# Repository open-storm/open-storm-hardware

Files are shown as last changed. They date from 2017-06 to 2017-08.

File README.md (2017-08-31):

# open-storm-hardware
Schematics for open storm hardware.

## perfect cell
**[perfect-cell]** contains Eagle schematics for the _perfect-cell_ board. This board is intended for use with the [perfect-cell](https://github.com/open-storm/perfect-cell) firmware. This board features:

- Cypress CY8C5888LTI-LP097 Programmable System-on-Chip
- Cortex M3 32-bit ARM processor
- 64 KB SRAM
- 256 KB Flash
- Support for Telit cellular modules
- 40 I/O pins for sensors and actuators

Cell Board

## level shifter and relay board
**[level-shifter]** contains Eagle schematics for a level shifter and relay board that can be used to interface the _perfect-cell_ board with higher voltage equipment (such as a valve or autosampler).

Relay board

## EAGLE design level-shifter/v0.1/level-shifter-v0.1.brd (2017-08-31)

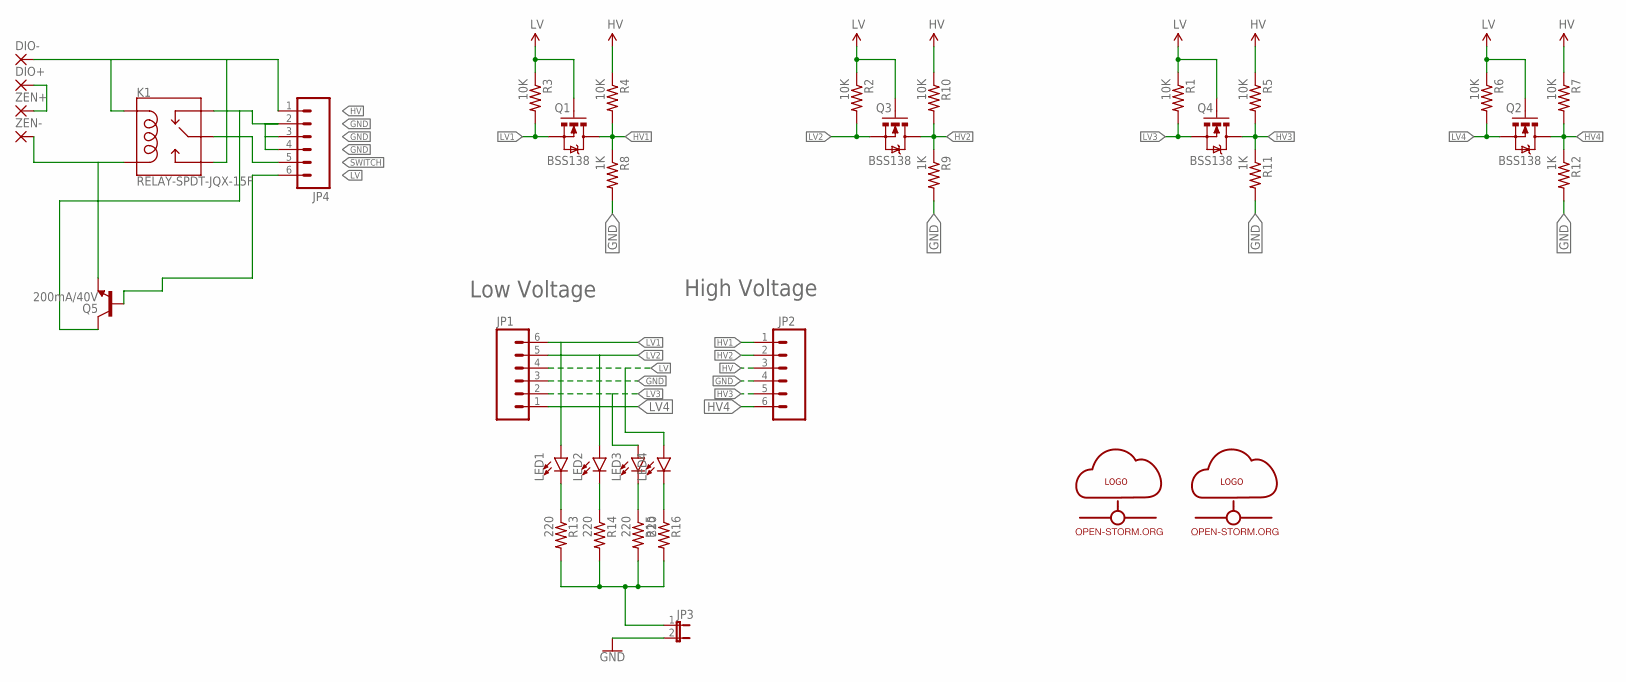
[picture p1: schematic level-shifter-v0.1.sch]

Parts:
DIO+: 2,15/1,0
DIO-: 2,15/1,0
JP1, JP2, JP4: M06SIP; 1X06
JP3: JUMPER-2PTH; 1X02
K1: RELAY-SPDT-JQX-15F; RELAY-T90
LED1, LED2, LED3, LED4: LED5MM; LED_5MM
Q1, Q2, Q3, Q4: BSS138; TO-92
Q5: 200mA/40V; TO-92
R1, R2, R3, R4, R5, R6, R7, R10: 10K; AXIAL-0.4
R8, R9, R11, R12: 1K; AXIAL-0.4
R13, R14, R15, R16: 220; AXIAL-0.4
U$1: OPEN-STORM-LOGO
U$2: OPEN-STORM-LOGO-SMALL
ZEN+: 2,15/1,0
ZEN-: 2,15/1,0

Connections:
GND: JP1.3, JP2.4, JP3.2, JP4.2, JP4.3, JP4.4, K1.NC, Q5.3 (C), R8.P$2 (2), R9.P$2 (2), R11.P$2 (2), R12.P$2 (2)
HV: DIO-.1, JP2.3, JP4.1, K1.COIL1, K1.NO, R4.P$1 (1), R5.P$1 (1), R7.P$1 (1), R10.P$1 (1)
HV1: JP2.1, Q1.1 (D), R4.P$2 (2), R8.P$1 (1)
HV2: JP2.2, Q3.1 (D), R9.P$1 (1), R10.P$2 (2)
HV3: JP2.5, Q4.1 (D), R5.P$2 (2), R11.P$1 (1)
HV4: JP2.6, Q2.1 (D), R7.P$2 (2), R12.P$1 (1)
LV: JP1.4, JP4.6, LED4.A, Q1.3 (G), Q2.3 (G), Q3.3 (G), Q4.3 (G), Q5.2 (B), R1.P$1 (1), R2.P$1 (1), R3.P$1 (1), R6.P$1 (1)
LV1: JP1.6, LED1.A, Q1.2 (S), R3.P$2 (2)
LV2: JP1.5, LED2.A, Q3.2 (S), R2.P$2 (2)
LV3: JP1.2, LED3.A, Q4.2 (S), R1.P$2 (2)
LV4: JP1.1, Q2.2 (S), R6.P$2 (2)
unnamed: DIO+.1, ZEN+.1
unnamed: LED4.K (C), R16.P$1 (1)
unnamed: LED2.K (C), R14.P$1 (1)
unnamed: K1.COIL2, Q5.1 (E), ZEN-.1
unnamed: LED1.K (C), R13.P$1 (1)
unnamed: LED3.K (C), R15.P$1 (1)
unnamed: JP3.1, R13.P$2 (2), R14.P$2 (2), R15.P$2 (2), R16.P$2 (2)
SWITCH: JP4.5, K1.MAIN

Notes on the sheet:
High Voltage
Low Voltage

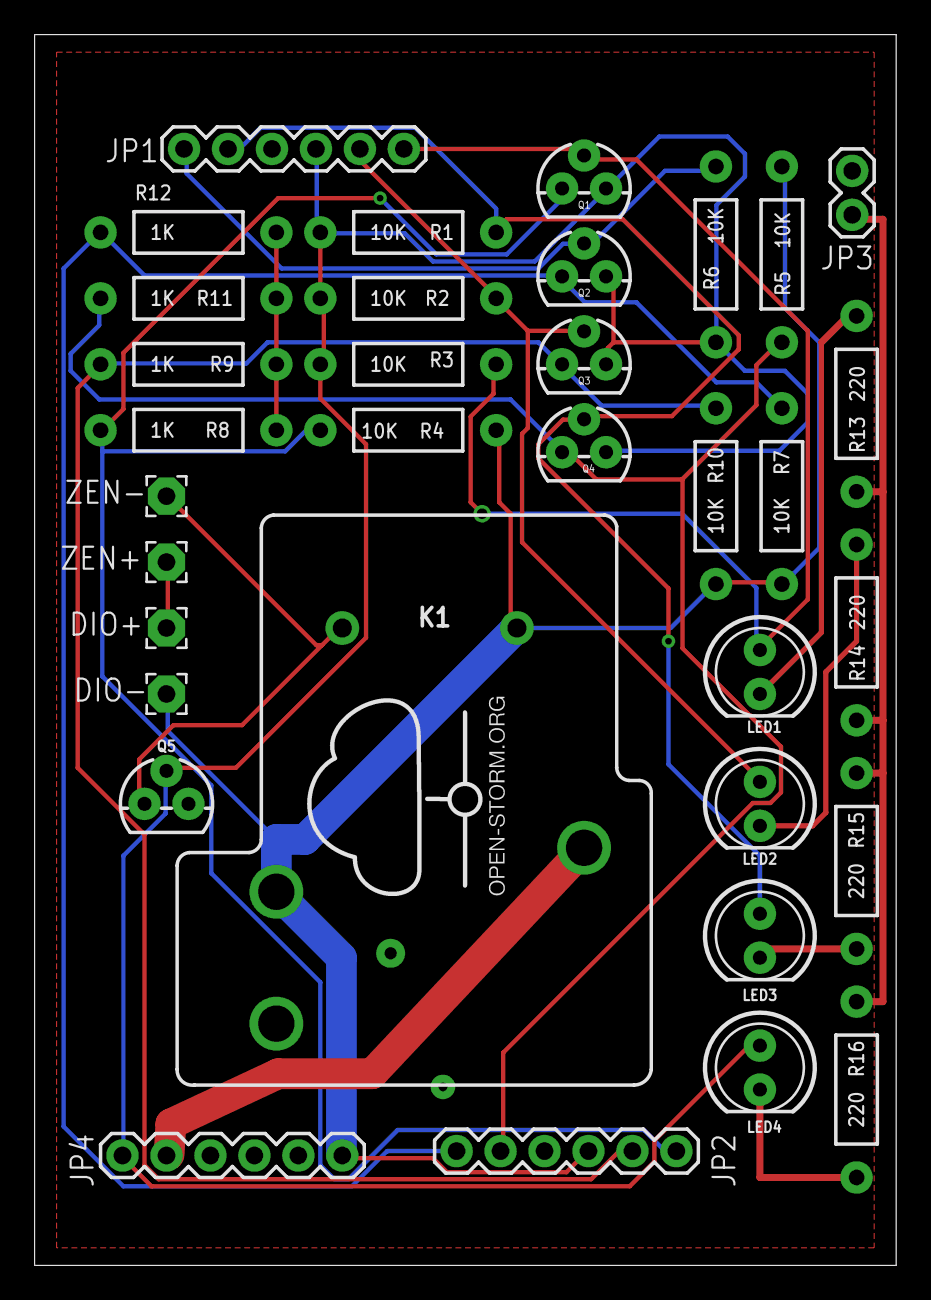
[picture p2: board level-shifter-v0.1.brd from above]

Board: 2 copper layers, 49.8 x 71.1 mm, 36 parts (1 on the bottom side), 19 nets.

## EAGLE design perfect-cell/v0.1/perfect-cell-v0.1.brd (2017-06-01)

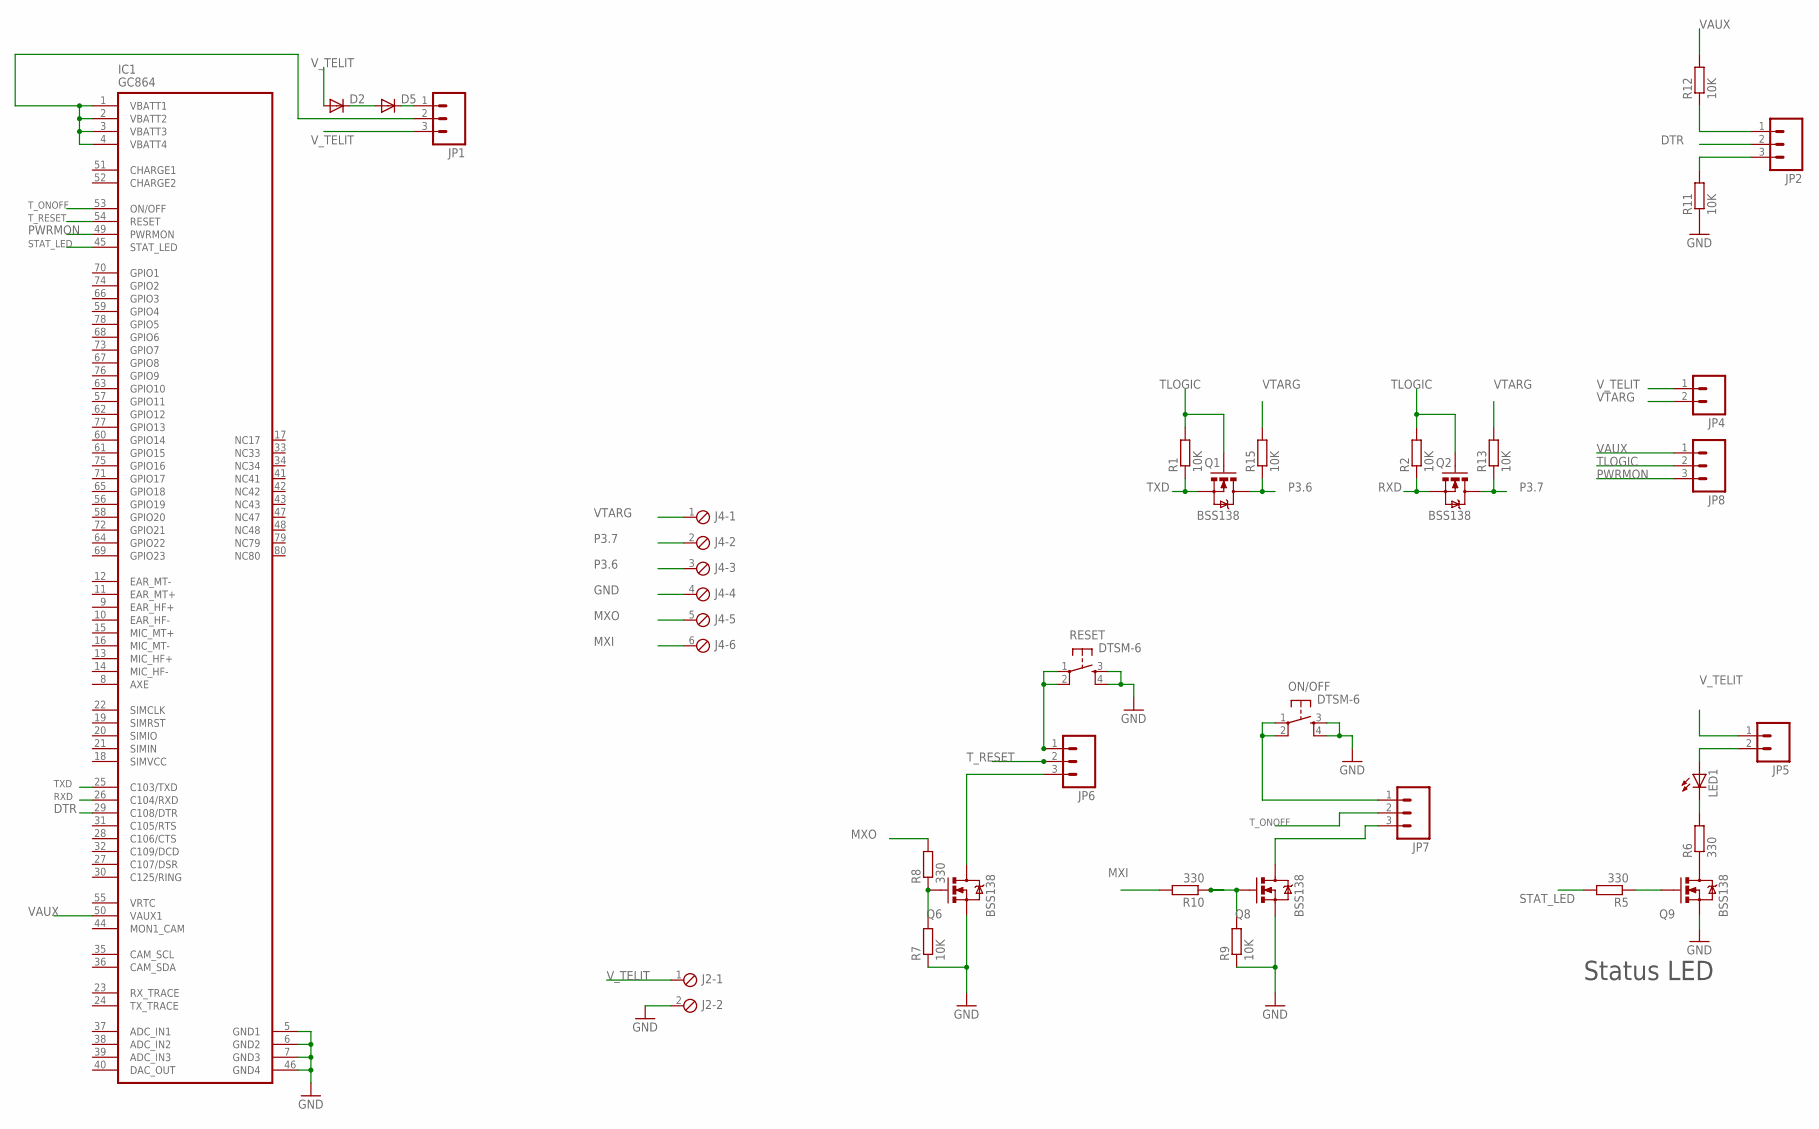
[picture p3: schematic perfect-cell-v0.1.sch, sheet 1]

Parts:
D2, D5: DIODESMA; SMA-DIODE
IC1: GC864
J2: MPT2; 2POL254
J4: MPT6; 6POL254
JP1, JP2, JP6, JP7, JP8: M03LOCK; 1X03_LOCK
JP4, JP5: M02LOCK; 1X02_LOCK
LED1: LEDSML0805; SML0805
ON/OFF: DTSM-6
Q1, Q2, Q6, Q8, Q9: BSS138; SOT23-3
R1, R2, R7, R9, R11, R12, R13, R15: 10K; R0805
R5, R6, R8, R10: 330; R0805
RESET: DTSM-6

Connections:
CHARGE1: IC1.51 (CHARGE1)
CHARGE2: IC1.52 (CHARGE2)
DTR: IC1.29 (C108/DTR), JP2.2
GND: IC1.5 (GND1), IC1.6 (GND2), IC1.7 (GND3), IC1.46 (GND4), J2.2, J4.4, ON/OFF.3, ON/OFF.4, Q6.2 (S), Q8.2 (S), Q9.2 (S), R7.1, R9.1, R11.1, RESET.3, RESET.4; also elsewhere on the board
MXI: J4.6, R10.2; also elsewhere on the board
MXO: J4.5, R8.2; also elsewhere on the board
unnamed: Q6.1 (G), R7.2, R8.1
unnamed: IC1.1 (VBATT1), IC1.2 (VBATT2), IC1.3 (VBATT3), IC1.4 (VBATT4), JP1.2
unnamed: D2.C, D5.A
unnamed: Q9.3 (D), R6.1
unnamed: JP5.2, LED1.A
unnamed: LED1.C, R6.2
unnamed: Q8.1 (G), R9.2, R10.1
unnamed: Q9.1 (G), R5.1
unnamed: JP2.1, R12.1
unnamed: JP2.3, R11.2
unnamed: D5.C, JP1.1
unnamed: JP7.3, Q8.3 (D)
unnamed: JP6.3, Q6.3 (D)
unnamed: JP7.1, ON/OFF.1, ON/OFF.2
unnamed: JP6.1, RESET.1, RESET.2
P3.6: J4.3, Q1.3 (D), R15.1; also elsewhere on the board
P3.7: J4.2, Q2.3 (D), R13.1; also elsewhere on the board
PWRMON: IC1.49 (PWRMON), JP8.3
RXD: IC1.26 (C104/RXD), Q2.2 (S), R2.1
STAT_LED: IC1.45 (STAT_LED), R5.2
TLOGIC: JP8.2, Q1.1 (G), Q2.1 (G), R1.2, R2.2
TXD: IC1.25 (C103/TXD), Q1.2 (S), R1.1
T_ONOFF: IC1.53 (ON/OFF), JP7.2
T_RESET: IC1.54 (RESET), JP6.2
VAUX: IC1.50 (VAUX1), JP8.1, R12.2
VTARG: J4.1, JP4.2, R13.2, R15.2
V_TELIT: D2.A, J2.1, JP1.3, JP4.1, JP5.1; also elsewhere on the board

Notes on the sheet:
Status LED

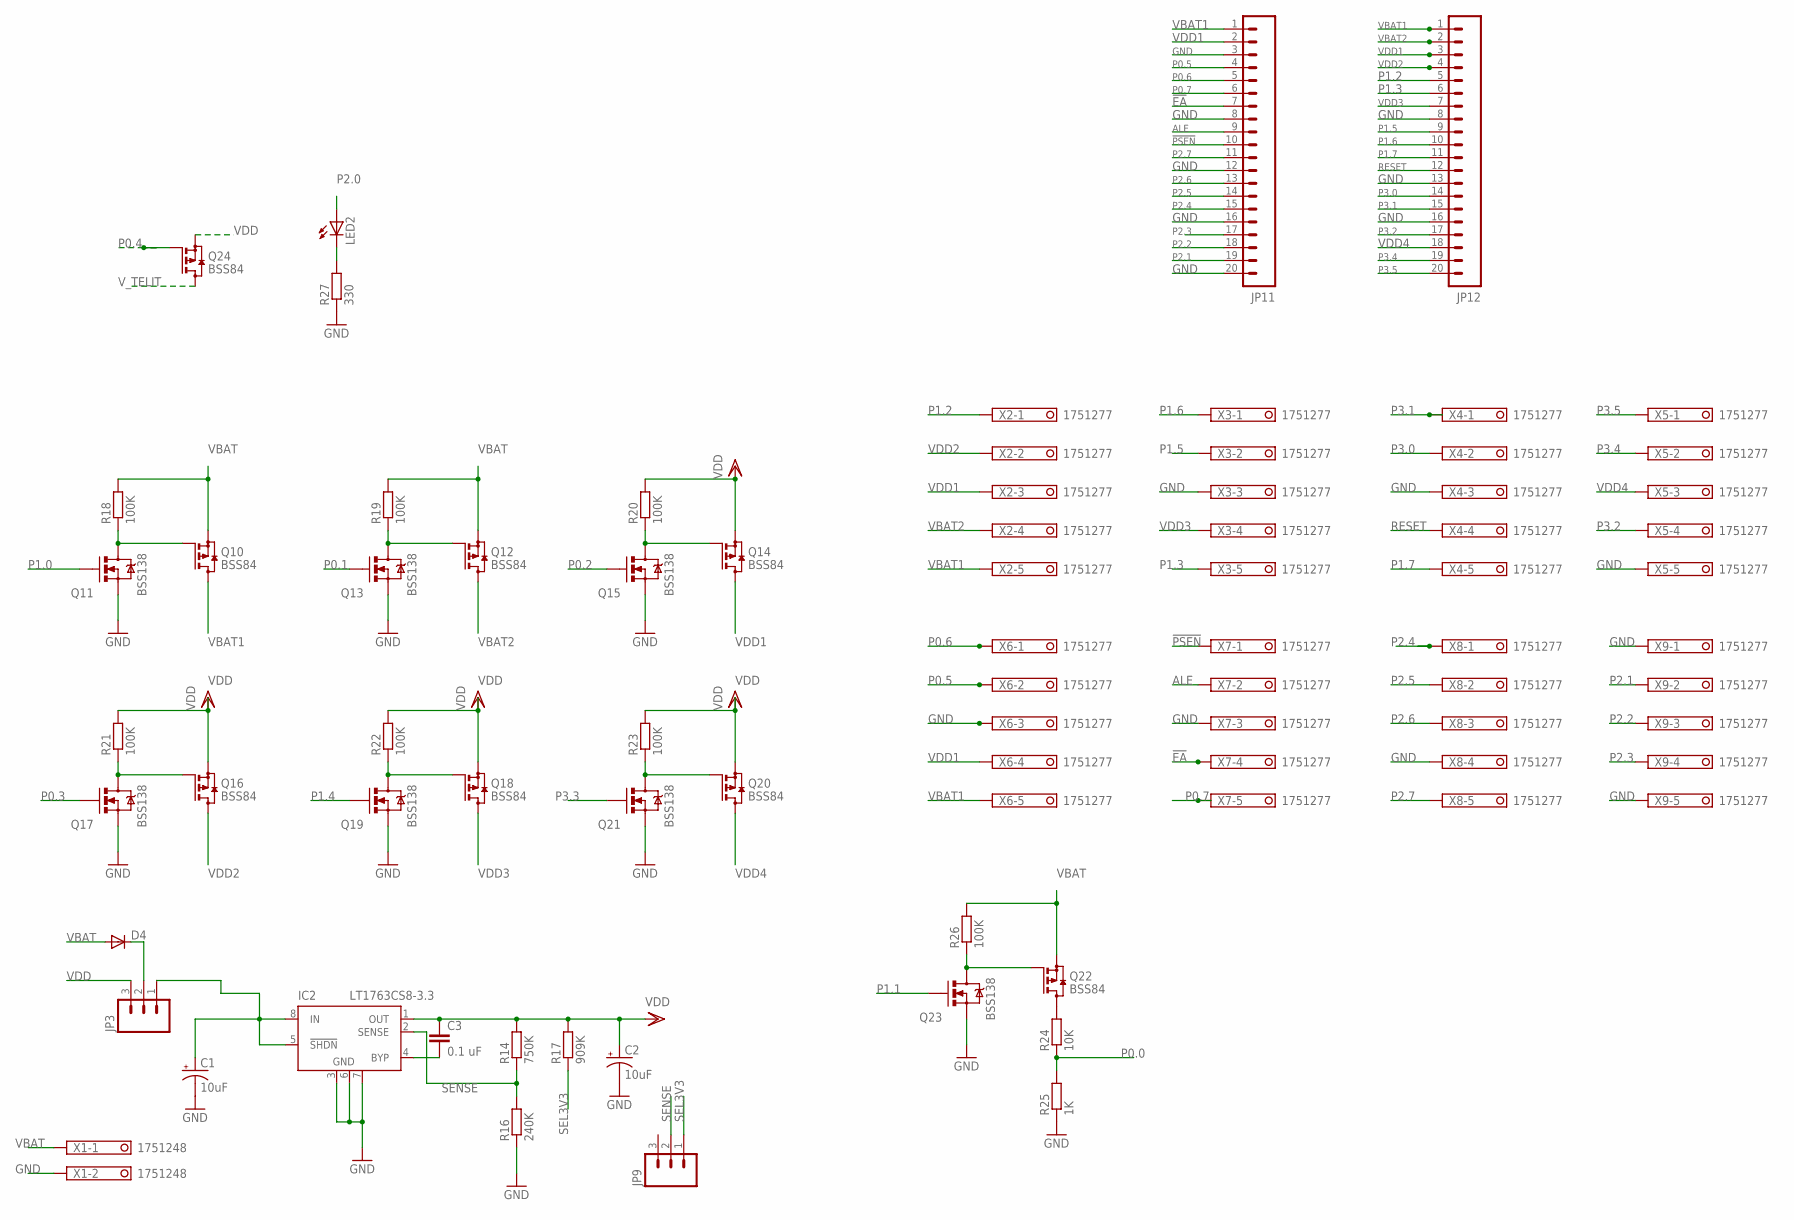
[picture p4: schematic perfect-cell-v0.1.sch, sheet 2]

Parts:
C1, C2: 10uF; EIA3216
C3: 0.1 uF; 0402-CAP
D4: DIODESMA; SMA-DIODE
IC2: LT1763CS8-3.3; SOIC8
JP3, JP9: M03LOCK; 1X03_LOCK
JP11, JP12: M20; 1X20
LED2: LEDSML0805; SML0805
Q10, Q12, Q14, Q16, Q18, Q20, Q22, Q24: BSS84; SOT23
Q11, Q13, Q15, Q17, Q19, Q21, Q23: BSS138; SOT23-3
R14: 750K; R0805
R16: 240K; R0805
R17: 909K; R0805
R18, R19, R20, R21, R22, R23, R26: 100K; R0805
R24: 10K; R0805
R25: 1K; R0805
R27: 330; R0805
X1: 1751248
X2, X3, X4, X5, X6, X7, X8, X9: 1751277

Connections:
!EA: JP11.7, X7.4; also elsewhere on the board
!PSEN: JP11.10, X7.1; also elsewhere on the board
ALE: JP11.9, X7.2; also elsewhere on the board
GND: C1.C (-), C2.C (-), IC2.3 (GND), IC2.6 (GND), IC2.7 (GND), JP11.3, JP11.8, JP11.12, JP11.16, JP11.20, JP12.8, JP12.13, JP12.16, Q11.2 (S), Q13.2 (S), Q15.2 (S), Q17.2 (S), Q19.2 (S), Q21.2 (S), Q23.2 (S), R16.1, R25.1, R27.1, X1.2, X3.3, X4.3, X5.5, X6.3, X7.3, X8.4, X9.1, X9.5; also elsewhere on the board
unnamed: D4.C, JP3.2
unnamed: Q10.1 (G), Q11.3 (D), R18.1
unnamed: C1.A (+), IC2.5 (!SHDN), IC2.8 (IN), JP3.1
unnamed: Q12.1 (G), Q13.3 (D), R19.1
unnamed: C3.2, IC2.4 (BYP)
unnamed: Q14.1 (G), Q15.3 (D), R20.1
unnamed: Q16.1 (G), Q17.3 (D), R21.1
unnamed: Q18.1 (G), Q19.3 (D), R22.1
unnamed: Q20.1 (G), Q21.3 (D), R23.1
unnamed: Q22.1 (G), Q23.3 (D), R26.1
unnamed: Q22.3 (D), R24.2
unnamed: LED2.C, R27.2
P0.0: R24.1, R25.2; also elsewhere on the board
P0.1: Q13.1 (G); also elsewhere on the board
P0.2: Q15.1 (G); also elsewhere on the board
P0.3: Q17.1 (G); also elsewhere on the board
P0.4: Q24.1 (G); also elsewhere on the board
P0.5: JP11.4, X6.2; also elsewhere on the board
P0.6: JP11.5, X6.1; also elsewhere on the board
P0.7: JP11.6, X7.5; also elsewhere on the board
P1.0: Q11.1 (G); also elsewhere on the board
P1.1: Q23.1 (G); also elsewhere on the board
P1.2: JP12.5, X2.1; also elsewhere on the board
P1.3: JP12.6, X3.5; also elsewhere on the board
P1.4: Q19.1 (G); also elsewhere on the board
P1.5: JP12.9, X3.2; also elsewhere on the board
P1.6: JP12.10, X3.1; also elsewhere on the board
P1.7: JP12.11, X4.5; also elsewhere on the board
P2.0: LED2.A; also elsewhere on the board
P2.1: JP11.19, X9.2; also elsewhere on the board
P2.2: JP11.18, X9.3; also elsewhere on the board
P2.3: JP11.17, X9.4; also elsewhere on the board
P2.4: JP11.15, X8.1; also elsewhere on the board
P2.5: JP11.14, X8.2; also elsewhere on the board
P2.6: JP11.13, X8.3; also elsewhere on the board
P2.7: JP11.11, X8.5; also elsewhere on the board
P3.0: JP12.14, X4.2; also elsewhere on the board
P3.1: JP12.15, X4.1; also elsewhere on the board
P3.2: JP12.17, X5.4; also elsewhere on the board
P3.3: Q21.1 (G); also elsewhere on the board
P3.4: JP12.19, X5.2; also elsewhere on the board
P3.5: JP12.20, X5.1; also elsewhere on the board
RESET: JP12.12, X4.4; also elsewhere on the board
SEL3V3: JP9.1, R17.1
SENSE: IC2.2 (SENSE), JP9.2, R14.1, R16.2
VBAT: D4.A, Q10.2 (S), Q12.2 (S), Q22.2 (S), R18.2, R19.2, R26.2, X1.1
VBAT1: JP11.1, JP12.1, Q10.3 (D), X2.5, X6.5
VBAT2: JP12.2, Q12.3 (D), X2.4
VDD: C2.A (+), C3.1, IC2.1 (OUT), JP3.3, Q14.2 (S), Q16.2 (S), Q18.2 (S), Q20.2 (S), Q24.2 (S), R14.2, R17.2, R20.2, R21.2, R22.2, R23.2; also elsewhere on the board
VDD1: JP11.2, JP12.3, Q14.3 (D), X2.3, X6.4
VDD2: JP12.4, Q16.3 (D), X2.2
VDD3: JP12.7, Q18.3 (D), X3.4
VDD4: JP12.18, Q20.3 (D), X5.3
V_TELIT: Q24.3 (D); also elsewhere on the board

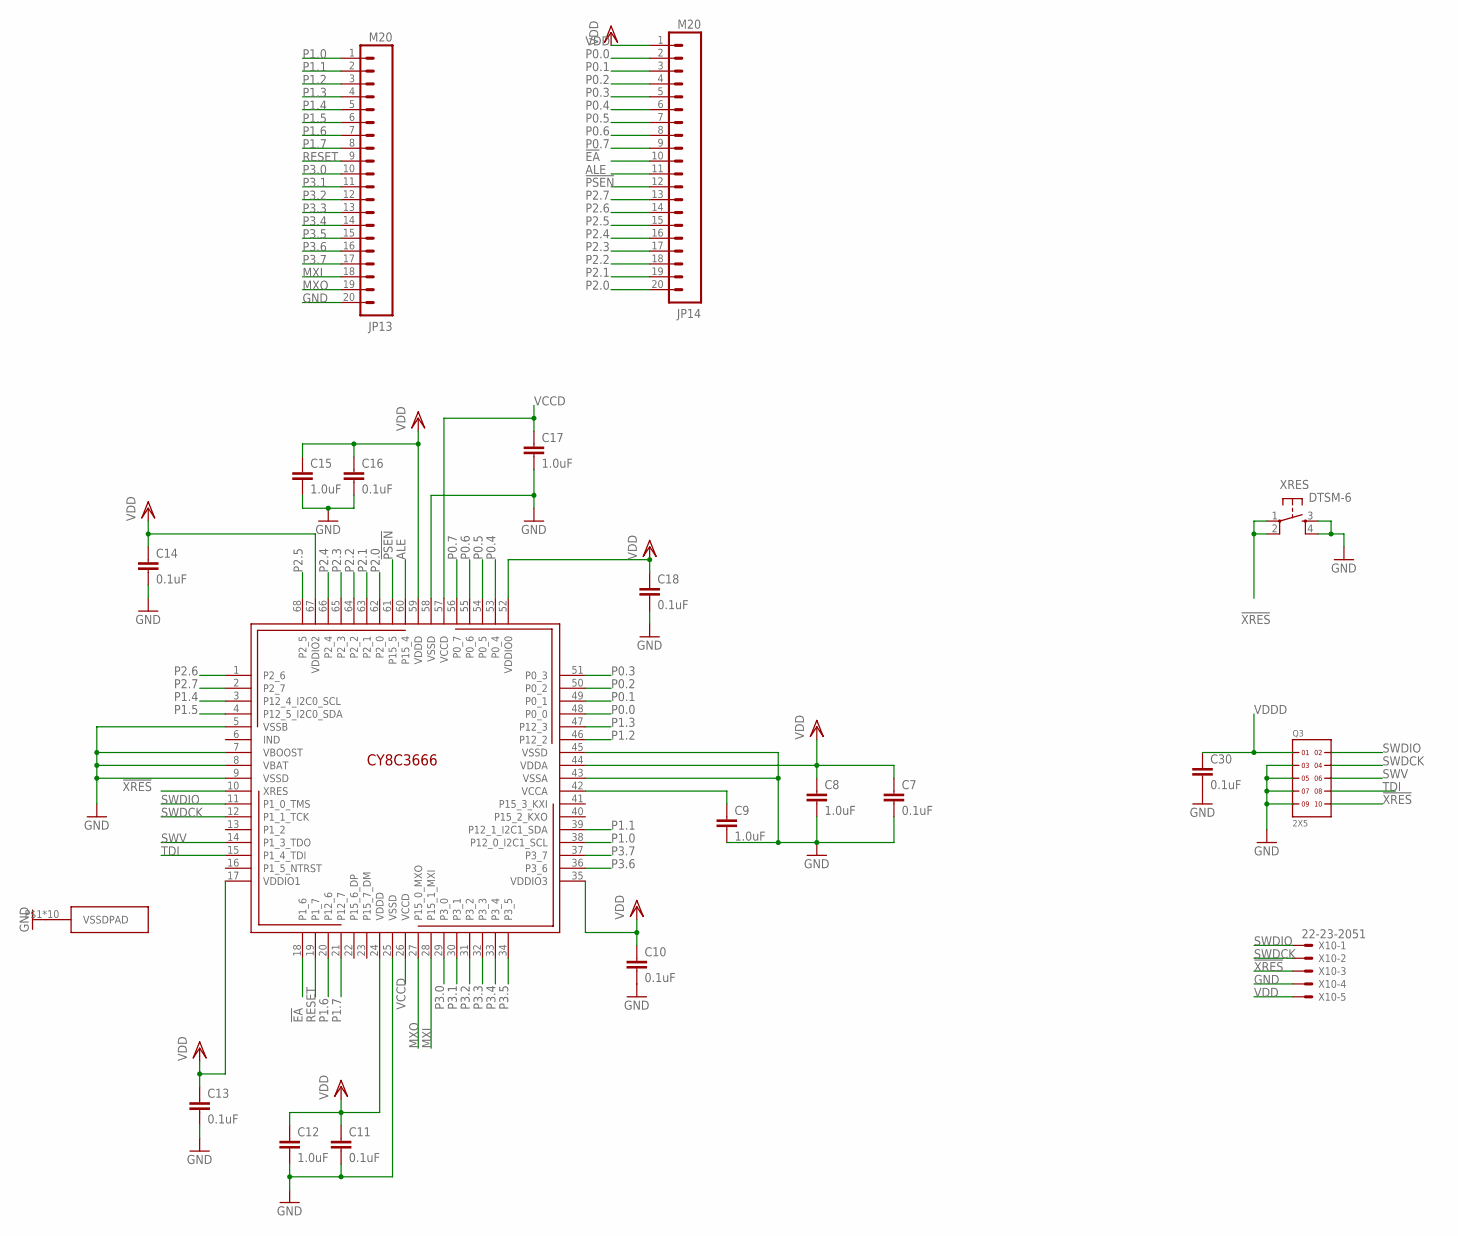
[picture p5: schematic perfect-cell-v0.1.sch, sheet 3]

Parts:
C7, C10, C11, C13, C14, C16, C18, C30: 0.1uF; 0402-CAP
C8, C9, C12, C15, C17: 1.0uF; 0402-CAP
JP13, JP14: M20; 1X20
Q3: 2X5; FTSH-105-01-XXX-DV-K
U$1: CY8C3X66LTI; QFN-68
X10: 22-23-2051
XRES: DTSM-6

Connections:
!EA: JP14.10, U$1.18 (P1_6); also elsewhere on the board
!PSEN: JP14.12, U$1.61 (P15_5); also elsewhere on the board
!XRES: Q3.10, U$1.10 (XRES), X10.3, XRES.1, XRES.2
ALE: JP14.11, U$1.60 (P15_4); also elsewhere on the board
GND: C7.2, C8.2, C9.2, C10.2, C11.2, C12.2, C13.2, C14.2, C15.2, C16.2, C17.2, C18.2, C30.2, JP13.20, Q3.3, Q3.5, Q3.7, Q3.9, U$1.5 (VSSB), U$1.7 (VBOOST), U$1.8 (VBAT), U$1.9 (VSSD), U$1.25 (VSSD), U$1.43 (VSSA), U$1.45 (VSSD), U$1.58 (VSSD), U$1.P$1 (VSSDPAD), U$1.P$2 (VSSDPAD), U$1.P$3 (VSSDPAD), U$1.P$4 (VSSDPAD), U$1.P$5 (VSSDPAD), U$1.P$6 (VSSDPAD), U$1.P$7 (VSSDPAD), U$1.P$8 (VSSDPAD), U$1.P$9 (VSSDPAD), U$1.PAD (VSSDPAD), X10.4, XRES.3, XRES.4; also elsewhere on the board
MXI: JP13.18, U$1.28 (P15_1_MXI); also elsewhere on the board
MXO: JP13.19, U$1.27 (P15_0_MXO); also elsewhere on the board
unnamed: C9.1, U$1.42 (VCCA)
P0.0: JP14.2, U$1.48 (P0_0); also elsewhere on the board
P0.1: JP14.3, U$1.49 (P0_1); also elsewhere on the board
P0.2: JP14.4, U$1.50 (P0_2); also elsewhere on the board
P0.3: JP14.5, U$1.51 (P0_3); also elsewhere on the board
P0.4: JP14.6, U$1.53 (P0_4); also elsewhere on the board
P0.5: JP14.7, U$1.54 (P0_5); also elsewhere on the board
P0.6: JP14.8, U$1.55 (P0_6); also elsewhere on the board
P0.7: JP14.9, U$1.56 (P0_7); also elsewhere on the board
P1.0: JP13.1, U$1.38 (P12_0_I2C1_SCL); also elsewhere on the board
P1.1: JP13.2, U$1.39 (P12_1_I2C1_SDA); also elsewhere on the board
P1.2: JP13.3, U$1.46 (P12_2); also elsewhere on the board
P1.3: JP13.4, U$1.47 (P12_3); also elsewhere on the board
P1.4: JP13.5, U$1.3 (P12_4_I2C0_SCL); also elsewhere on the board
P1.5: JP13.6, U$1.4 (P12_5_I2C0_SDA); also elsewhere on the board
P1.6: JP13.7, U$1.20 (P12_6); also elsewhere on the board
P1.7: JP13.8, U$1.21 (P12_7); also elsewhere on the board
P2.0: JP14.20, U$1.62 (P2_0); also elsewhere on the board
P2.1: JP14.19, U$1.63 (P2_1); also elsewhere on the board
P2.2: JP14.18, U$1.64 (P2_2); also elsewhere on the board
P2.3: JP14.17, U$1.65 (P2_3); also elsewhere on the board
P2.4: JP14.16, U$1.66 (P2_4); also elsewhere on the board
P2.5: JP14.15, U$1.68 (P2_5); also elsewhere on the board
P2.6: JP14.14, U$1.1 (P2_6); also elsewhere on the board
P2.7: JP14.13, U$1.2 (P2_7); also elsewhere on the board
P3.0: JP13.10, U$1.29 (P3_0); also elsewhere on the board
P3.1: JP13.11, U$1.30 (P3_1); also elsewhere on the board
P3.2: JP13.12, U$1.31 (P3_2); also elsewhere on the board
P3.3: JP13.13, U$1.32 (P3_3); also elsewhere on the board
P3.4: JP13.14, U$1.33 (P3_4); also elsewhere on the board
P3.5: JP13.15, U$1.34 (P3_5); also elsewhere on the board
P3.6: JP13.16, U$1.36 (P3_6); also elsewhere on the board
P3.7: JP13.17, U$1.37 (P3_7); also elsewhere on the board
RESET: JP13.9, U$1.19 (P1_7); also elsewhere on the board
SWDCK: Q3.4, U$1.12 (P1_1_TCK), X10.2
SWDIO: Q3.2, U$1.11 (P1_0_TMS), X10.1
SWV: Q3.6, U$1.14 (P1_3_TDO)
TDI: Q3.8, U$1.15 (P1_4_TDI)
VCCD: C17.1, U$1.26 (VCCD), U$1.57 (VCCD)
VDD: C7.1, C8.1, C10.1, C11.1, C12.1, C13.1, C14.1, C15.1, C16.1, C18.1, JP14.1, U$1.17 (VDDIO1), U$1.24 (VDDD), U$1.35 (VDDIO3), U$1.44 (VDDA), U$1.52 (VDDIO0), U$1.59 (VDDD), U$1.67 (VDDIO2), X10.5; also elsewhere on the board
VDDD: C30.1, Q3.1

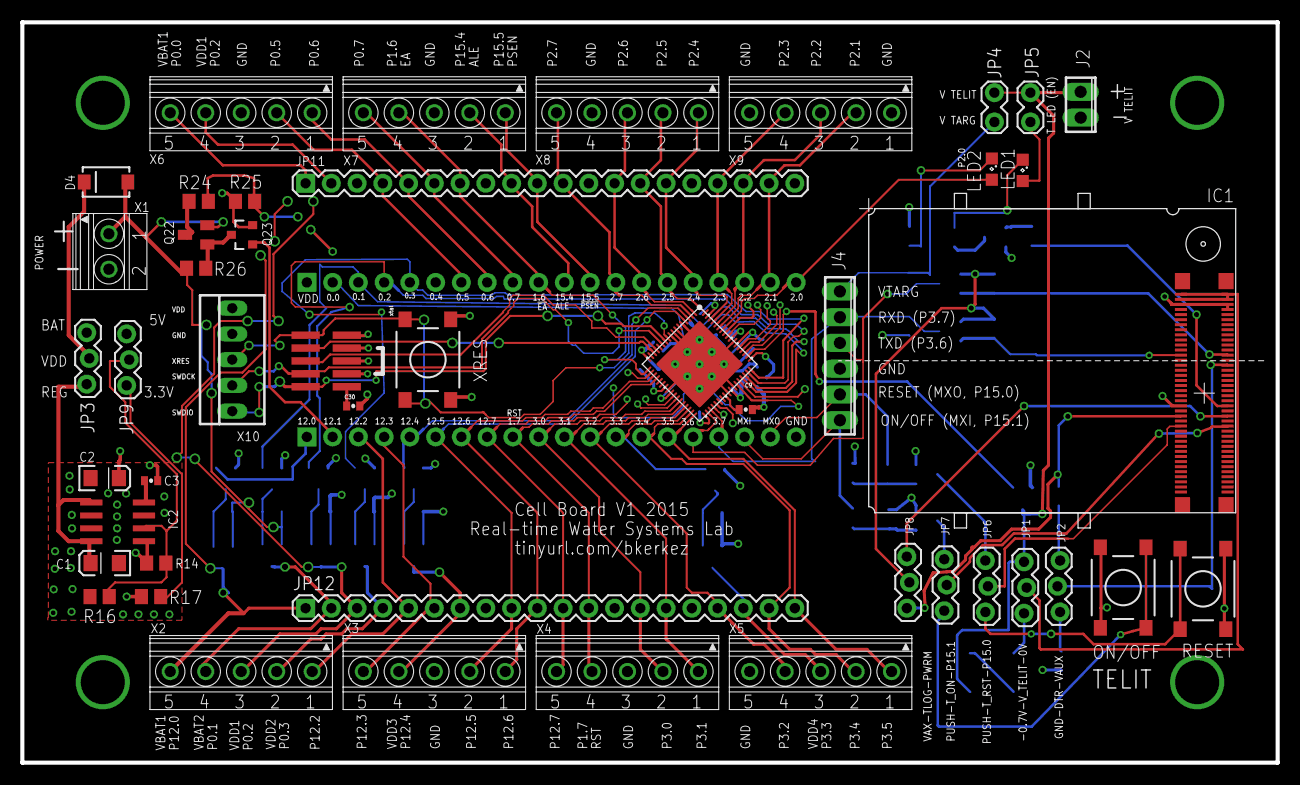
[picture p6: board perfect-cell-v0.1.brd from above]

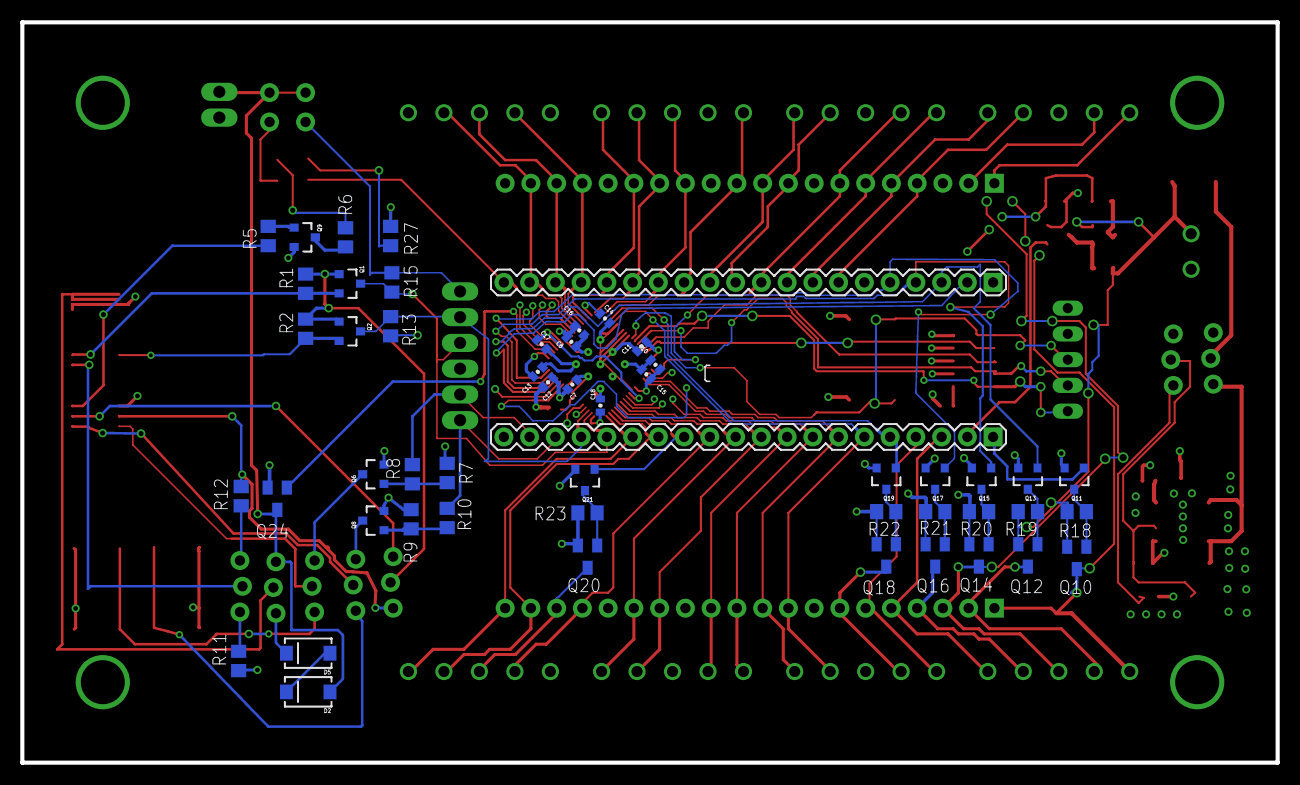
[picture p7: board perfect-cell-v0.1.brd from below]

Board: 4 copper layers, 123.8 x 73.0 mm, 98 parts (52 on the bottom side), 95 nets.

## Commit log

2017-06-01 Initial commit of perfect-cell-v0.1
    [perfect-cell-v0.1.brd, perfect-cell-v0.1.sch]
2017-08-31 Add level shifter board
    [level-shifter-v0.1.brd, level-shifter-v0.1.sch]

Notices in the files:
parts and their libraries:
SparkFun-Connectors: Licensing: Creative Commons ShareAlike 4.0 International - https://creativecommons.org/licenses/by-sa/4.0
